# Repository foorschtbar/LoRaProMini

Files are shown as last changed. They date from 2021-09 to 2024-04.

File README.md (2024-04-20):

# LoRaProMini - A low power LoRaWAN Node

[









](https://github.com/foorschtbar/LoRaProMini)

A LoRaWAN sensor node, based on ATmega328P MCU (Arduino Pro Mini) and RFM95W/SX1276 LoRa Transceiver.

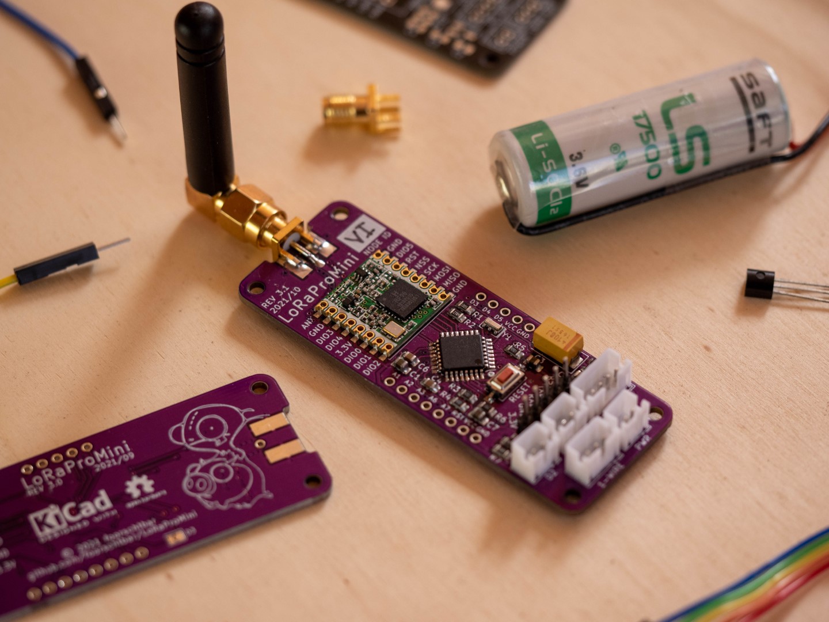
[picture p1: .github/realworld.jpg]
PCB Front Assembled


The module can be used:

- Collect various climate values with environmental sensors. See [Environmental (Weather/Clima) Sensor](#environmental-weatherclima-sensor)
- Tell if the letter carrier has put new letters in your mailbox. See [Mailbox Monitor](#mailbox-monitor)
- Notify if someone rang the doorbell
- Act a wirless button
- and many more...

## Features

- Deep sleep MCU and sensors between data transmissions
- Two interrupt inputs could use to wake up the MCU and sensors from deep sleep
- Confirmend und unconfirmend data up messages
- Ultra low power consumption. Under 10μA with all features and sensors
- Power input 3.5-6V:
  - Battery (Li-Ion or Li-SOCl2 works fine)
  - Battery with solar charger
- Sensor support
  - Bosch BME280 (humidity, barometric pressure and ambient temperature)
  - Maxim DS18B20(+)/DS18S20(+)/DS1822 1-Wire temperature sensor

### Warning

LoRaProMini does not take care of the compliance with the duty cycle limitation. Please select only transmission intervals that are within the legal limits (1%/0.1%). Please also note that the interrupt inputs may cause additional transmissions if this function is activated.

### PCB Ordering

:point_up: I still have a few PCBs left. If you are interested please contact me. Contact details can be found here: https://github.com/foorschtbar or visit my Tindie store:



## Example Applications

### Environmental (Weather/Clima) Sensor

- Download [Radiation Shield STL](https://www.prusaprinters.org/prints/73421-radiation-shield-for-diy-weather-station)
- Buy [Waterproof LED Solar Light](https://s.click.aliexpress.com/e/_9AKunB)

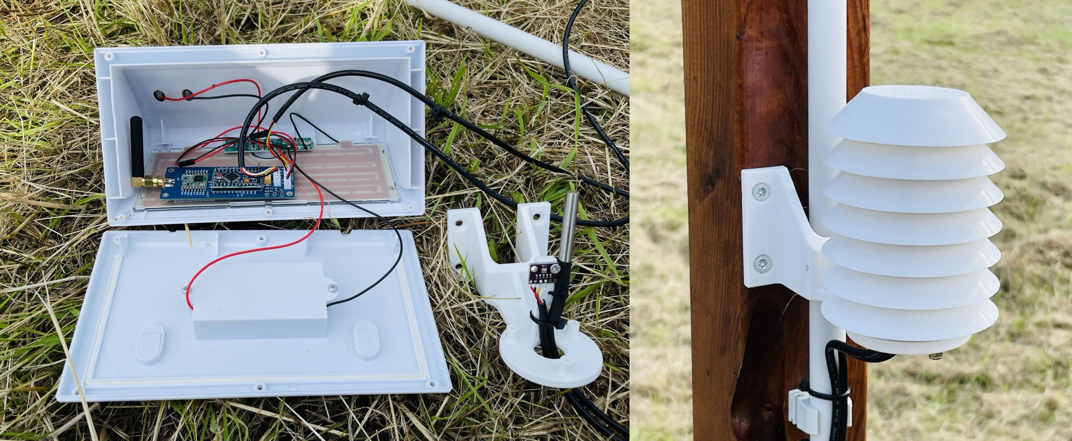
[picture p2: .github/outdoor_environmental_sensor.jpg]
Outdoor Clima Sensor


### Mailbox Monitor

- Download [Case STL](https://www.prusaprinters.org/prints/132941-case-for-lorawan-mailbox-monitor-lorapromini)
- Buy [Normally Opened Reed Switches](https://s.click.aliexpress.com/e/_AU1hN3)

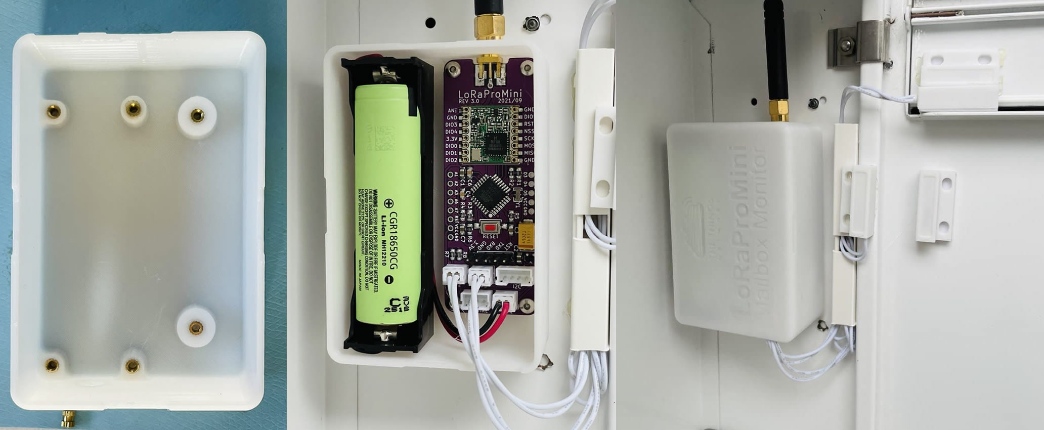
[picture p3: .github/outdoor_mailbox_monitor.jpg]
Mailbox Monitor


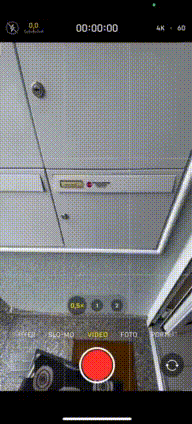
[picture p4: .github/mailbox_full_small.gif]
Mailbox Monitor
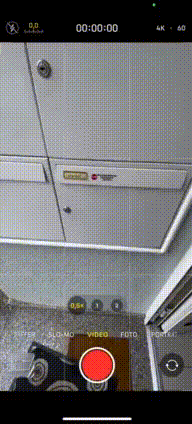
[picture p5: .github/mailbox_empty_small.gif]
Mailbox Monitor
 

## More pics

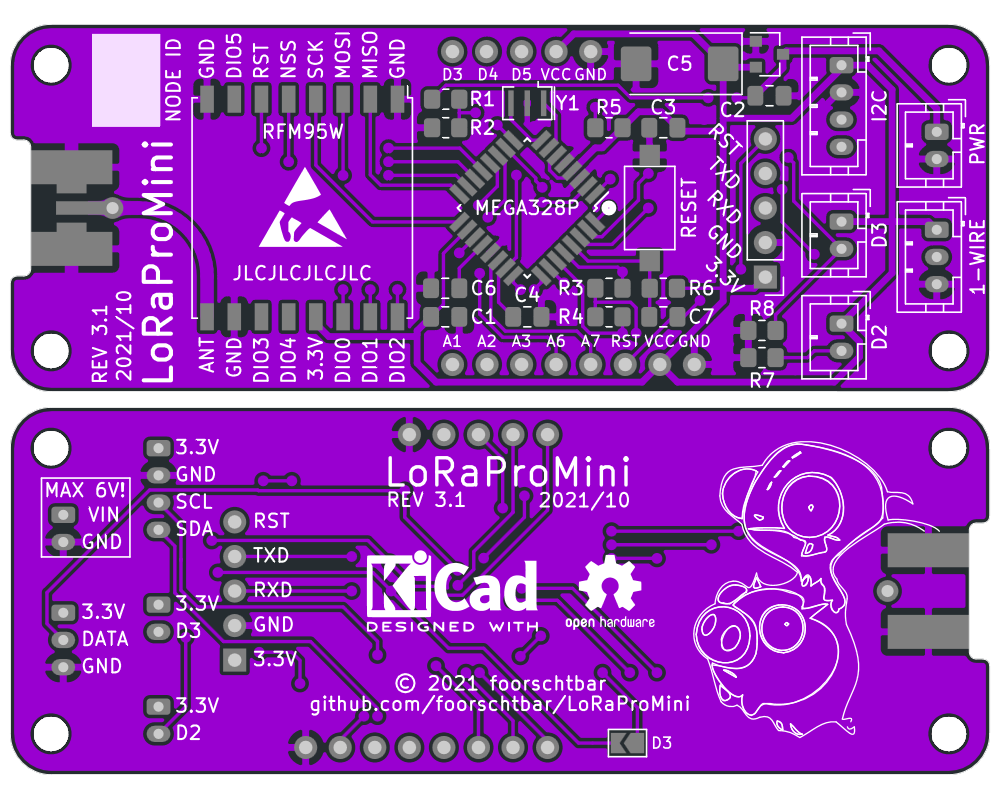
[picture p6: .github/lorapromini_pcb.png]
PCB Front and Back


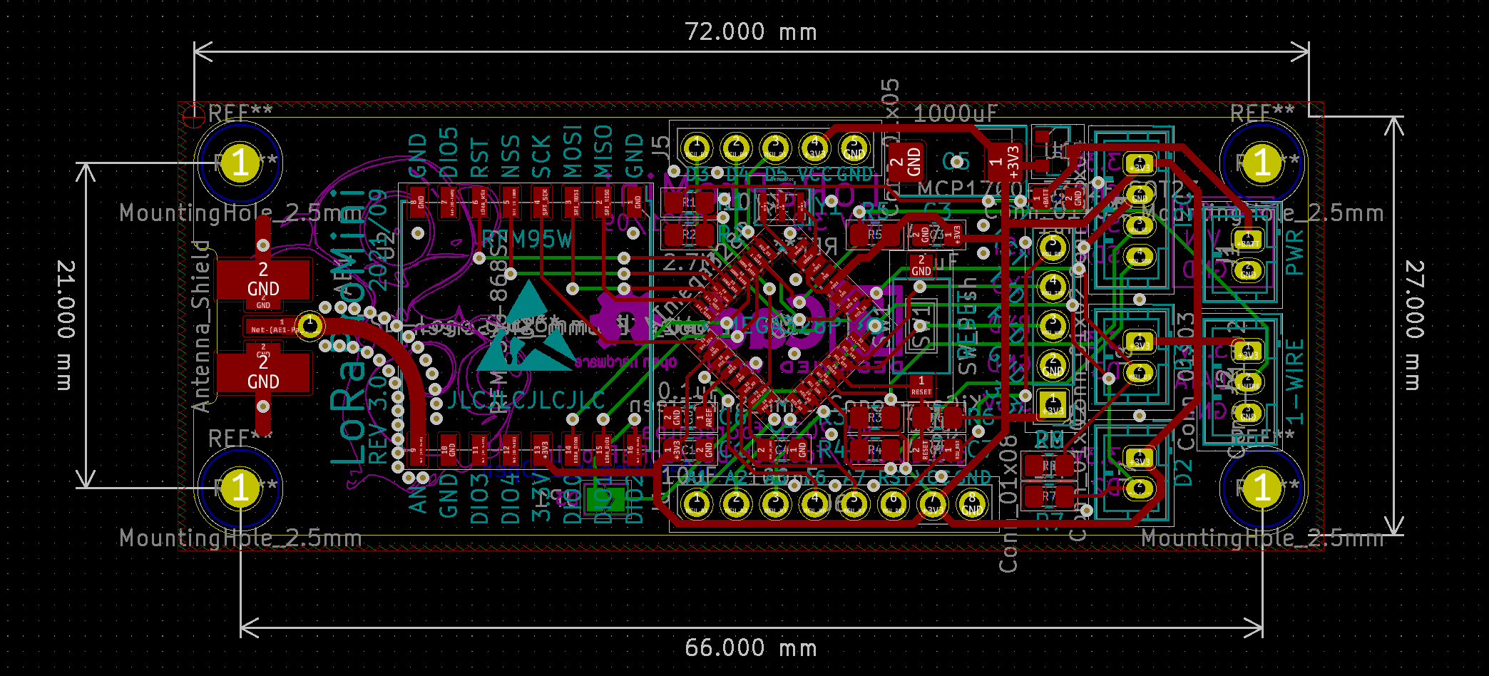
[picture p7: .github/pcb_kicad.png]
PCB KiCad


## The Things Stack configuration

- LoRaWAN version `MAC V1.0.3`

## How to use

1. Manufacture the PCB. Here you find the [Gerber](pcb) files
1. Assemble the PCB. Here you find the [Bill of Materials](https://foorschtbar.github.io/LoRaProMini/pcb/bom/ibom.html) (BOM)
   - **Attention:** The current version (v3.1) of the PCB has no ISP header! A pre-burned Atmega328P must be installed. I got one from an Arduino Pro Mini Board (3.3V 8 Mhz), because a completely assembled Arduino is cheaper than a single chip
1. Flash config firmware (See [How to flash](#how-to-flash))
1. Start voltage calibration from menu
1. Start configuration builder [Configuration Builder](https://foorschtbar.github.io/LoRaProMini/configbuilder)
1. Measure the voltage with a multimeter
1. Insert multimeter voltage and the analog value in the Volts-per-bit (VPB) calculator to get VPB factor.
1. If u have a adjustable power supply, try different voltages to find best factor. Warning: The maximum voltage is 6 Volt
1. Fill out the other fields like activation methode, session keys and EUIs
1. Write configuration to EEPROM using configuration menu
1. Check written configuration via configuration menu
1. Flash debug or release firmware (See [How to flash](#how-to-flash))
1. Finish

## How to flash

```
avrdude-F -v -c arduino -p atmega328p -P <COM PORT> -b 57600 -D -U flash:w:<FIRMWARE FILE>:i
```

Example:

```
avrdude -F -v -c arduino -p atmega328p -P COM4 -b 57600 -D -U flash:w:firmware_1.0_config.hex:i
```

## Firmware Changelog

### Version 2.7

- Fixed a problem of resetting the interrupt trigger too early.

### Version 2.6

- Second attempt to solve the unnecessary delay due to the duty cycle limitation. Overflow of timer0 freezes the MCU after around 20 transmissions.

### Version 2.5

- Fixed problem with duty cycle limitation
- Fixed MCU deepsleep inaccuracy

### Version 2.4

- An external interrupt during a transmission terminates the transmission and starts a new transmission.
- Enabled Link Check Mode

### Version 2.3

- Fixed Typo

### Version 2.2

- An additional send delay between 0 and 20s has been added to avoid overlaps between different nodes with exactly the same send interval
- Some flash memory optimizations

### Version 2.1

- Improved (debug) logging to serial output
- BME sends -127°C (link DS18x) if no sensor was found

### Version 2.0

- Added wake up trough interrupt pins
- Added option for disable interrupt pins
- Added option for confirmed uplink
- Changed LoRaWAN data up message
  - Added state of interrupt pins
  - Combined major and minor version byte into a single byte (4 bits for major and 4 bits for minor)

### Version 1.1

- Only for testing CI Pipeline

### Version 1.0

- Initial Version

## PCB Changelog

### Version 3.2

- Fixed C7 (Replaced 10uF with 100nF)

### Version 3.1

- Added white field to specify the Node ID

### Version 3.0

- Removed Arduino Pro Mini Dauther PCB
- Added ATMEGA328P direct to the PCB
- Added pins for unused GPIOs
- Added D2 and D3 with Pulldowns and connector as external interrupts (need FW v2.0 or higher)

### Version 2.2

- Added RST pin to connector for programming

### Version 2.1

- Added connector for programming

### Version 2.0

- Smaller PCB
- Rounded Edges
- Fixed issue with DS18x onboard pin mapping

### Version 1.0

- Initial PCB

## TTS Payload Formatter (formerly TTN Payload Decoder)

```javascript
function decodeUplink(input) {
  var bytes = input.bytes;

  var itrTrigger = (bytes[0] & 0x1) !== 0; // Message was triggered from interrupt (bit 0)
  var itr0 = (bytes[0] & 0x2) !== 0; // Interrupt 0 (bit 1)
  var itr1 = (bytes[0] & 0x4) !== 0; // Interrupt 1 (bit 2)
  var bat = (bytes[1] << 8) | bytes[2]; // Battery
  var fwversion = (bytes[3] >> 4) + "." + (bytes[3] & 0xf); // Firmware version
  var temp1 = (bytes[4] & 0x80 ? 0xffff << 16 : 0) | (bytes[4] << 8) | bytes[5]; // BME Temperature
  var humi1 = (bytes[6] << 8) | bytes[7]; // BME Humidity
  var press1 = (bytes[8] << 8) | bytes[9]; // BME Pressure
  var temp2 =
    (bytes[10] & 0x80 ? 0xffff << 16 : 0) | (bytes[10] << 8) | bytes[11]; // DS18x Temperature

  var mbStatus = "UNKNOWN";
  if (itr0) {
    mbStatus = "FULL";
  } else if (itr1) {
    mbStatus = "EMPTY";
  }

  return {
    data: {
      interrupts: {
        itr0: itr0,
        itr1: itr1,
        itrTrigger: itrTrigger,
      },
      extra: {
        mbStatus: mbStatus,
        mbChanged: itrTrigger,
      },
      fwversion: fwversion,
      bme: {
        temperature: temp1 / 100,
        humidity: humi1 / 100,
        pressure: press1,
      },
      ds18x: {
        temperature: temp2 / 100,
      },
      battery: bat / 100,
    },
    warnings: [],
    errors: [],
  };
}
```

## ToDo

- [ ] Go to sleep immediately when voltage is too low
- [ ] Multi point calibration for battery voltage
- [ ] Set ADR (On/Off)
- [ ] Set SF (7-12)
- [ ] Allow change of NetID
- [x] Add wake up trough interrupt pins
- [x] Move Major- and Minorversion byte to single byte. 4 bits for major and 4 bits for minor.
- [x] Add option for Confirmed Uplink to config
- [x] Add CI/CD pipeline to build firmware
- [x] Rewirte VBP calculator in Configuration Builder
- [x] Move config to EEPROM
- [x] Added special firmware to change configs
- [x] Build HTML/JS Interface to build configs
- [x] Add CRC32 check
- [x] Test ABP
- [x] Test OTAA
- [x] Deploy config tool via GitHub Pages
- [x] Fix problem when checksum in pastend config had zeros O.o
- [x] Add random EUI generator button to config tool
- [x] Parse config string to GUI fields

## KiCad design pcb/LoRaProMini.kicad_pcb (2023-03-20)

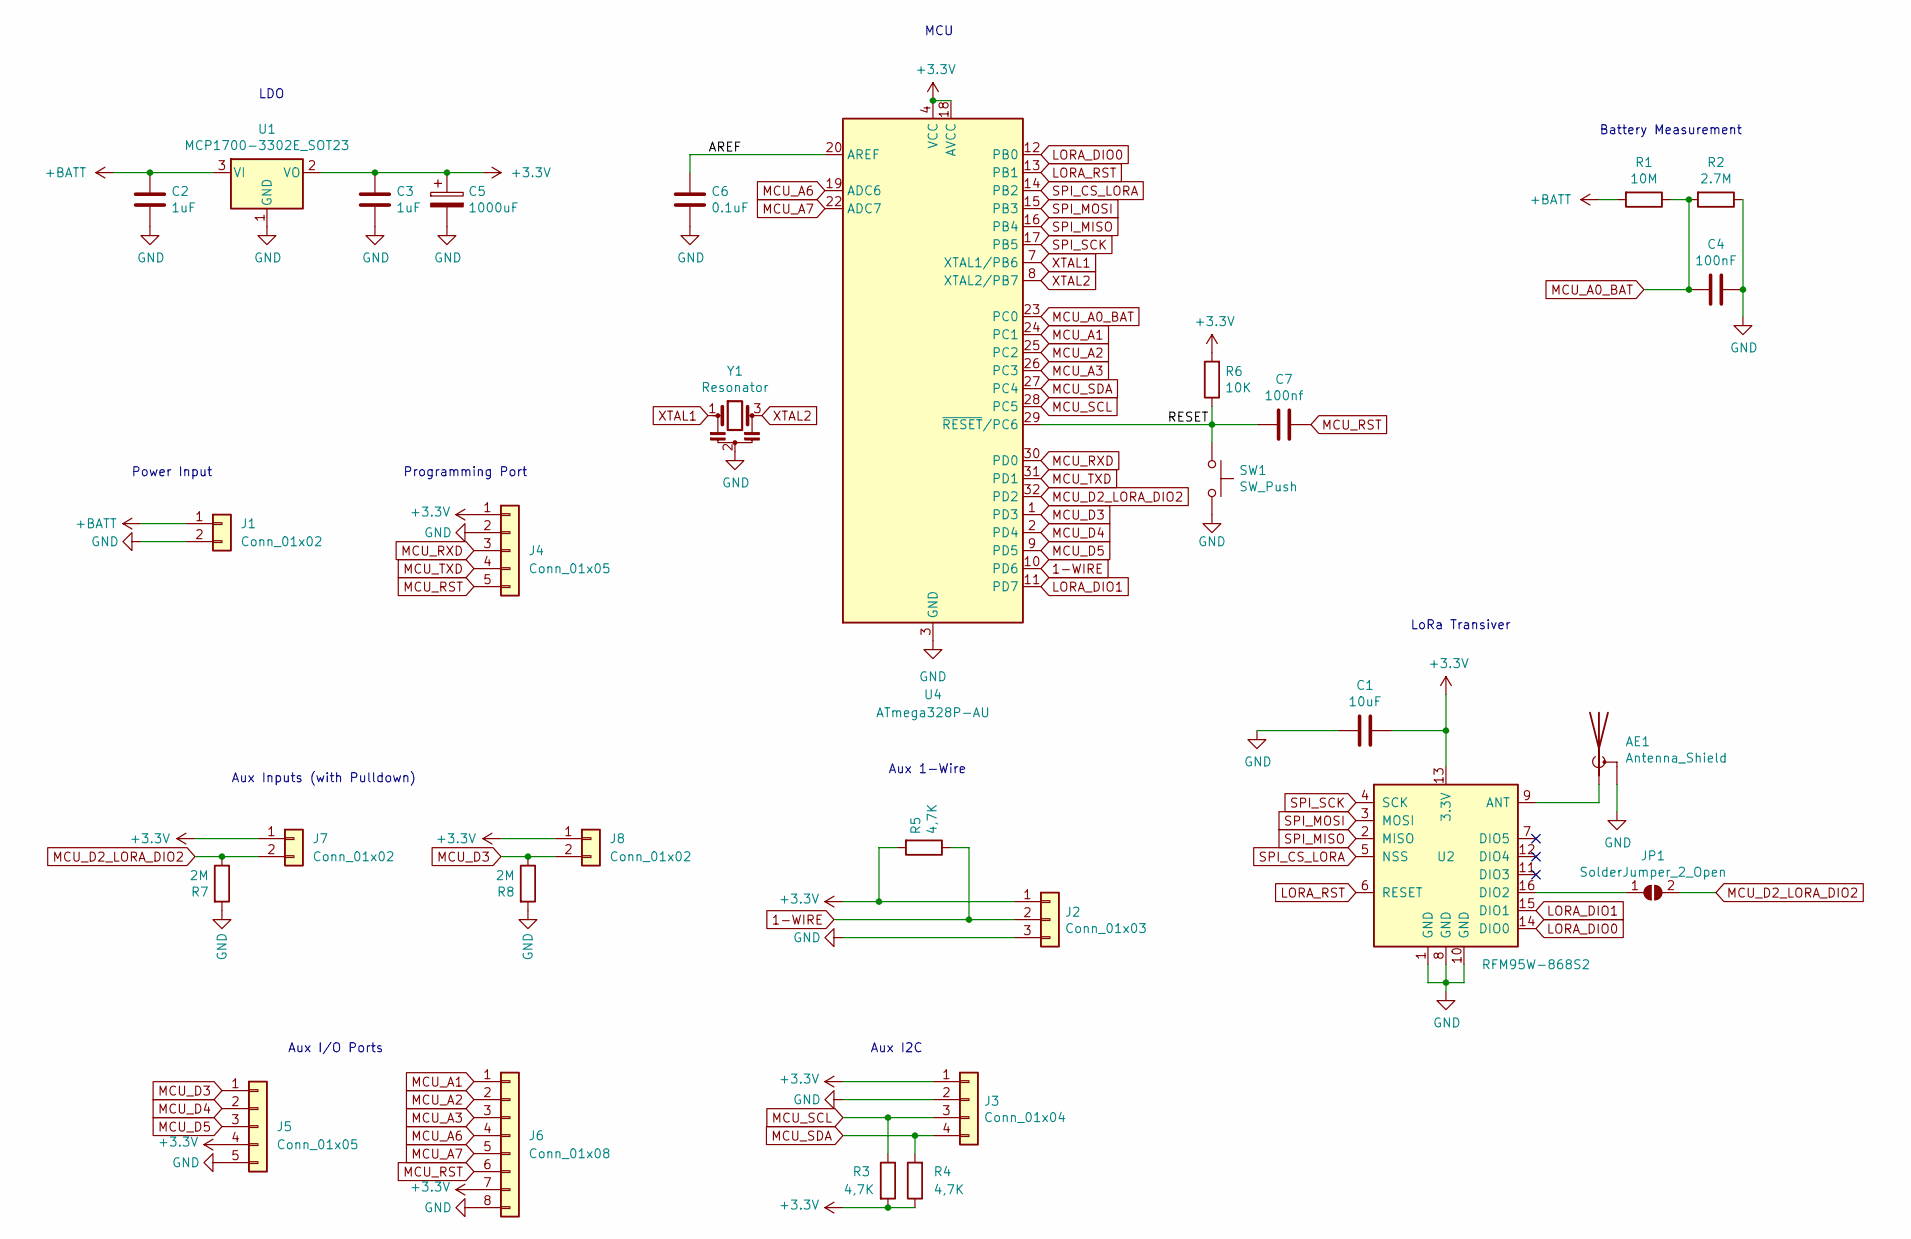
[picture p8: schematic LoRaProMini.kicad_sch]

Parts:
AE1: Antenna_Shield; Antenna_SMA_uFL
C1: 10uF; C_0805_2012Metric_Pad1.18x1.45mm_HandSolder
C2, C3: 1uF; C_0805_2012Metric_Pad1.18x1.45mm_HandSolder
C4: 100nF; C_0805_2012Metric_Pad1.18x1.45mm_HandSolder
C5: 1000uF; CP_EIA-7343-43_Kemet-X_Pad2.25x2.55mm_HandSolder
C6: 0.1uF; C_0805_2012Metric_Pad1.18x1.45mm_HandSolder
C7: 100nf; C_0805_2012Metric_Pad1.18x1.45mm_HandSolder
J1, J7, J8: Conn_01x02; JST_PH_B2B-PH-K_1x02_P2.00mm_Vertical
J2: Conn_01x03; JST_PH_B3B-PH-K_1x03_P2.00mm_Vertical
J3: Conn_01x04; JST_PH_B4B-PH-K_1x04_P2.00mm_Vertical
J4: Conn_01x05; PinHeader_1x05_P2.54mm_Vertical
J5: Conn_01x05; Holes_1x05_P2.54mm
J6: Conn_01x08; Holes_1x08_P2.54mm
JP1: SolderJumper_2_Open; SolderJumper-2_P1.3mm_Open_TrianglePad1.0x1.5mm
R1: 10M; R_0805_2012Metric_Pad1.20x1.40mm_HandSolder
R2: 2.7M; R_0805_2012Metric_Pad1.20x1.40mm_HandSolder
R3, R4, R5: 4,7K; R_0805_2012Metric_Pad1.20x1.40mm_HandSolder
R6: 10K; R_0805_2012Metric_Pad1.20x1.40mm_HandSolder
R7, R8: 2M; R_0805_2012Metric_Pad1.20x1.40mm_HandSolder
SW1: SW_Push; SW_SPST_CK_RS282G05A3
U1: MCP1700-3302E_SOT23; SOT-23
U2: RFM95W-868S2; HOPERF_RFM9XW_SMD
U4: ATmega328P-AU; TQFP-32_7x7mm_P0.8mm
Y1: Resonator; Resonator_SMD_Murata_CSTxExxV-3Pin_3.0x1.1mm

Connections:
1-WIRE: J2.2, R5.1, U4.10 (PD6)
+3.3V: C1.1, C3.1, C5.1, J2.1, J3.1, J4.1, J5.4, J6.7, J7.1, J8.1, R3.2, R4.1, R5.2, R6.2, U1.2 (VO), U2.13 (3.3V), U4.4 (VCC), U4.6 (VCC), U4.18 (AVCC)
+BATT: C2.1, J1.1, R1.2, U1.3 (VI)
/AREF: C6.1, U4.20 (AREF)
/RESET: C7.2, R6.1, SW1.1, U4.29 (~RESET/PC6)
GND: AE1.2 (Shield), C1.2, C2.2, C3.2, C4.1, C5.2, C6.2, J1.2, J2.3, J3.2, J4.2, J5.5, J6.8, R2.1, R7.2, R8.2, SW1.2, U1.1 (GND), U2.1 (GND), U2.8 (GND), U2.10 (GND), U4.3 (GND), U4.5 (GND), U4.21 (GND), Y1.2
LORA_DIO0: U2.14 (DIO0), U4.12 (PB0)
LORA_DIO1: U2.15 (DIO1), U4.11 (PD7)
LORA_RST: U2.6 (RESET), U4.13 (PB1)
MCU_A0_BAT: C4.2, R1.1, R2.2, U4.23 (PC0)
MCU_A1: J6.1, U4.24 (PC1)
MCU_A2: J6.2, U4.25 (PC2)
MCU_A3: J6.3, U4.26 (PC3)
MCU_A6: J6.4, U4.19 (ADC6)
MCU_A7: J6.5, U4.22 (ADC7)
MCU_D2_LORA_DIO2: J7.2, JP1.2 (B), R7.1, U4.32 (PD2)
MCU_D3: J5.1, J8.2, R8.1, U4.1 (PD3)
MCU_D4: J5.2, U4.2 (PD4)
MCU_D5: J5.3, U4.9 (PD5)
MCU_RST: C7.1, J4.5, J6.6
MCU_RXD: J4.3, U4.30 (PD0)
MCU_SCL: J3.3, R3.1, U4.28 (PC5)
MCU_SDA: J3.4, R4.2, U4.27 (PC4)
MCU_TXD: J4.4, U4.31 (PD1)
unnamed: AE1.1 (A), U2.9 (ANT)
unnamed: JP1.1 (A), U2.16 (DIO2)
SPI_CS_LORA: U2.5 (NSS), U4.14 (PB2)
SPI_MISO: U2.2 (MISO), U4.16 (PB4)
SPI_MOSI: U2.3 (MOSI), U4.15 (PB3)
SPI_SCK: U2.4 (SCK), U4.17 (PB5)
XTAL1: U4.7 (XTAL1/PB6), Y1.1
XTAL2: U4.8 (XTAL2/PB7), Y1.3

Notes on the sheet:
Aux 1-Wire
Aux I/O Ports
LDO
MCU
Power Input
Battery Measurement
Aux I2C
Aux Inputs (with Pulldown)
Programming Port
LoRa Transiver

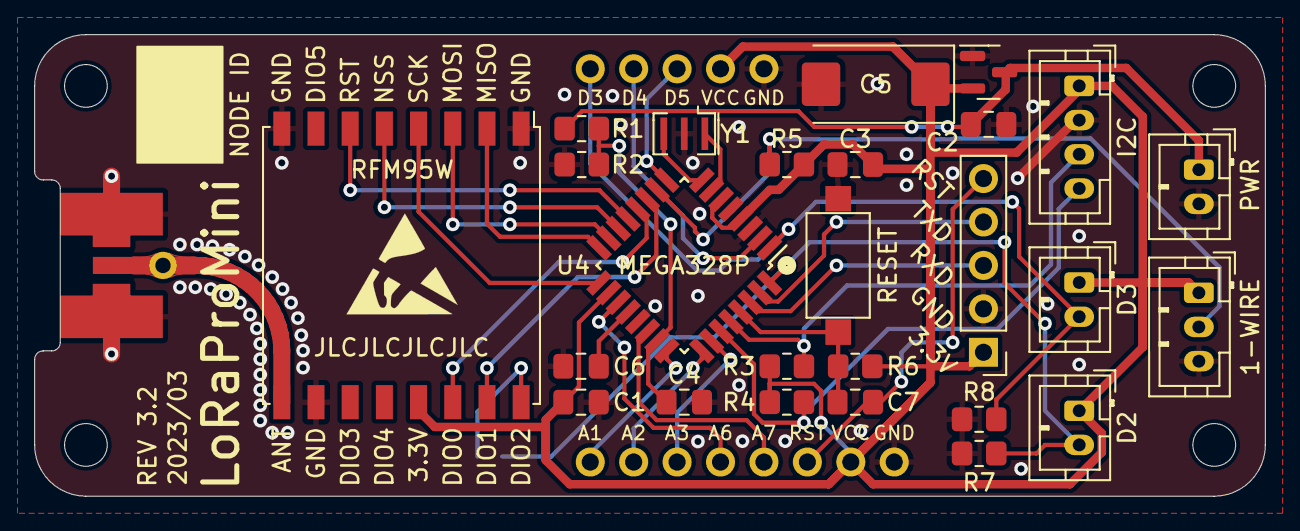
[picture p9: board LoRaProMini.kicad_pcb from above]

Board: 2 copper layers, 72.0 x 27.0 mm, 30 parts (1 on the bottom side), 32 nets.

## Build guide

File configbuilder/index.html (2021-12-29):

LoRaProMini Configuration Builder

All fields are mandatory!

Sleep time between transmissions in seconds (2 byte)

Adjustment for voltage divider (Volts per bit, 4 bytes)

Minimum voltage for operation, otherwise the node continues sleeping (4 bytes)

Wakeup from sleep through external interrupt pins (1 byte)

Confirmation for Data Up (1 byte)

Activation method (1 byte)

Network Session Key (MSB, 16 bytes)

App Session Key (MSB, 16 bytes)

Device Address (MSB, 4 bytes)

Application EUI (MSB, 8 bytes)

Device EUI (MSB, 8 bytes)

Application Key (MSB, 16 bytes)

Configuration

Size without checksum

Size with checksum

Checksum (CRC32)

© 2021 foorschtbar | GitHub (https://github.com/foorschtbar/LoRaProMini)

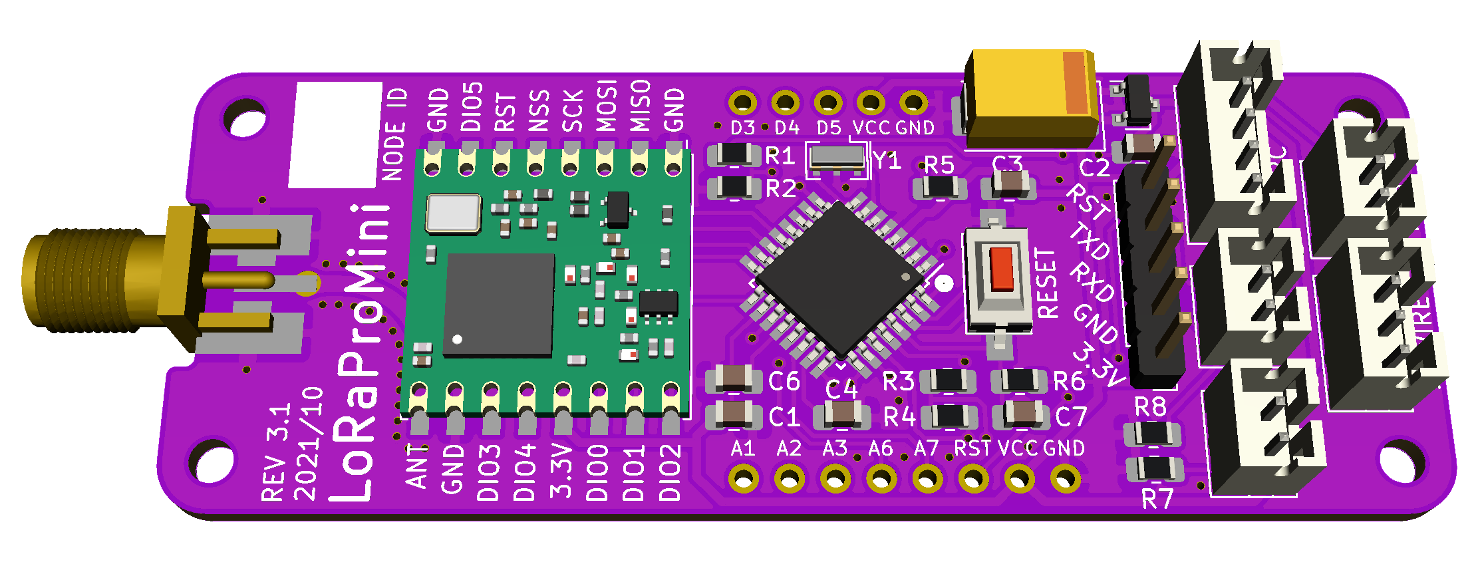
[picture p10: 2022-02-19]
.github/pcb_front_assembled.png

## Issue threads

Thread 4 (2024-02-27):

3.2 PCB Gerbers produce a 3.1 version at PCB house

radiohound, 2024-02-27:
Hello,

When I upload the 3.2 gerber zip file, my board house shows me a silkscreen with v3.1 on it. It looks like some layer or layers need to be updated to 3.2.

Closed 2024-02-29.

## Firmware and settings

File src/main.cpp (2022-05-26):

#include <Arduino.h>
#include <lmic.h>
#include <hal/hal.h>
#include <SPI.h>
#include <Wire.h>
#include <LowPower.h>
#include <OneWire.h>
#include <TinyDallas.h>
#include <TinyBME.h>
#include <EEPROM.h>
#include <CRC32.h>

// ++++++++++++++++++++++++++++++++++++++++
//
// CONSTANTS
//
// ++++++++++++++++++++++++++++++++++++++++

// LoRa module pins
#define LORA_DIO0 8
#define LORA_DIO1 7
#define LORA_DIO2 LMIC_UNUSED_PIN
#define LORA_RESET 9
#define LORA_CS SS

// 1-Wire Bus
#define ONEWIREBUS 6

// External interrupt pins
#define INTERRUPT_PIN0 2
#define INTERRUPT_PIN1 3

// Battery
#define BAT_SENSE_PIN A0 // Analoge Input Pin

// BME I2C Adresses
#define I2C_ADR_BME 0x76

// Voltage calibration interval
#define VOL_DEBUG_INTERVAL 1000 // in ms

// Start address in EEPROM for structure 'cfg'
#define CFG_START 0

// Config size
#define CFG_SIZE 82
#define CFG_SIZE_WITH_CHECKSUM 86

// LORA MAX RANDOM SEND DELAY
#define LORA_MAX_RANDOM_SEND_DELAY 20

// ++++++++++++++++++++++++++++++++++++++++
//
// LOGGING
//
// ++++++++++++++++++++++++++++++++++++++++

#ifdef LOG_DEBUG
#define log_d(s, ...) Serial.print(s, ##__VA_ARGS__);
#define log_d_ln(s, ...) Serial.println(s, ##__VA_ARGS__);
#define logHex_d(b, c) printHex(b, c);
const boolean LOG_DEBUG_ENABLED = true;
#else
#define log_d(s, ...)
#define log_d_ln(s, ...)
#define logHex_d(b, c)
const boolean LOG_DEBUG_ENABLED = false;
#endif

// ++++++++++++++++++++++++++++++++++++++++
//
// LIBS
//
// ++++++++++++++++++++++++++++++++++++++++

OneWire oneWire(ONEWIREBUS);
TinyDallas ds(&oneWire);
TinyBME bme;

// Dallas temp sensor(s)
DeviceAddress dsSensor; // Holds later first sensor found at boot.

// ++++++++++++++++++++++++++++++++++++++++
//
// ENUMS
//
// ++++++++++++++++++++++++++++++++++++++++

enum _activationMethode
{
  OTAA = 1,
  ABP = 2
};

enum _StateByte
{
  STATE_ITR_TRIGGER = 0b0001,
  STATE_ITR0 = 0b0010,
  STATE_ITR1 = 0b0100,
};

// ++++++++++++++++++++++++++++++++++++++++
//
// VARS
//
// ++++++++++++++++++++++++++++++++++++++++

#ifdef CONFIG_MODE
const boolean CONFIG_MODE_ENABLED = true;
#else
const boolean CONFIG_MODE_ENABLED = false;
#endif

// LoRa LMIC
static osjob_t sendjob;
const lmic_pinmap lmic_pins = {
    .nss = LORA_CS,
    .rxtx = LMIC_UNUSED_PIN,
    .rst = LORA_RESET,
    .dio = {LORA_DIO0, LORA_DIO1, LORA_DIO2},
};

typedef struct
{
  uint8_t CONFIG_IS_VALID;          // 1 byte
  uint16_t SLEEPTIME;               // 2 byte - (Deep) Sleep time between data acquisition and transmission
  float BAT_SENSE_VPB;              // 4 byte - Volts per Bit. See documentation
  float BAT_MIN_VOLTAGE;            // 4 byte - Minimum voltage for operation, otherwise the node continues to sleep
  uint8_t WAKEUP_BY_INTERRUPT_PINS; // 1 byte - 0 = Disabled, 1 = Enabled
  uint8_t CONFIRMED_DATA_UP;        // 1 byte - 0 = Unconfirmed Data Up, 1 = Confirmed Data Up
  uint8_t ACTIVATION_METHOD;        // 1 byte - 1 = OTAA, 2 = ABP

  // ABP
  u1_t NWKSKEY[16]; // 16 byte - NwkSKey, network session key in big-endian format (aka msb).
  u1_t APPSKEY[16]; // 16 byte - AppSKey, application session key in big-endian format (aka msb).
  u4_t DEVADDR;     //  4 byte - DevAddr, end-device address in big-endian format (aka msb)
  // OTAA
  u1_t APPEUI[8];  //  8 byte - EUIs must be little-endian format, so least-significant-byte (aka lsb)
  u1_t DEVEUI[8];  //  8 byte - EUIs must be in little-endian format, so least-significant-byte (aka lsb)
  u1_t APPKEY[16]; // 16 byte - AppSKey, application session key in big-endian format (aka msb).

} configData_t;
configData_t cfg; // Instance 'cfg' is a global variable with 'configData_t' structure now

volatile boolean wakedFromISR0 = false;
volatile boolean wakedFromISR1 = false;
unsigned long lastPrintTime = 0;
unsigned long prepareCount = 0;
boolean TXCompleted = false;
boolean foundBME = false; // BME Sensor found. To skip reading if no sensor is attached
boolean foundDS = false;  // DS19x Sensor found. To skip reading if no sensor is attached
byte pinState = 0x0;
boolean doSend = false;

// These callbacks are used in over-the-air activation
void os_getArtEui(u1_t *buf)
{
  memcpy(buf, cfg.APPEUI, 8);
}
void os_getDevEui(u1_t *buf)
{
  memcpy(buf, cfg.DEVEUI, 8);
}
void os_getDevKey(u1_t *buf)
{
  memcpy(buf, cfg.APPKEY, 16);
}

// ++++++++++++++++++++++++++++++++++++++++
//
// MAIN CODE
//
// ++++++++++++++++++++++++++++++++++++++++

void clearSerialBuffer()
{
  while (Serial.available())
  {
    Serial.read();
  }
}

void wakeUp0()
{
  wakedFromISR0 = true;
}

void wakeUp1()
{
  wakedFromISR1 = true;
}

float readBat()
{
  uint16_t value = 0;
  uint8_t numReadings = 5;

  for (uint8_t i = 0; i < numReadings; i++)
  {
    value = value + analogRead(BAT_SENSE_PIN);

    // 1ms pause adds more stability between reads.
    delay(1);
  }

  value = value / numReadings;

  float batteryV = value * cfg.BAT_SENSE_VPB;
  if (CONFIG_MODE_ENABLED)
  {
    Serial.print(F("Analoge voltage: "));
    Serial.print(((1.1 / 1024.0) * value), 2);
    Serial.print(F(" V | Analoge value: "));
    Serial.print(value);
    Serial.print(F(" ("));
    Serial.print(((100.0 / 1023.0) * value), 1);
    Serial.print(F("% of Range) | Battery voltage: "));
    Serial.print(batteryV, 1);
    Serial.print(F(" V ("));
    Serial.print(batteryV, 2);
    Serial.print(F(" V, VPB="));
    Serial.print(cfg.BAT_SENSE_VPB, 10);
    Serial.println(F(")"));
  }

  return batteryV;
}

void printHex(byte buffer[], size_t arraySize)
{
  unsigned c;
  for (size_t i = 0; i < arraySize; i++)
  {
    c = buffer[i];

    if (i != 0)
      Serial.write(32); // Space

    c &= 0xff;
    if (c < 16)
      Serial.write(48); // 0
    Serial.print(c, HEX);
  }
}

void readConfig()
{
  EEPROM.get(CFG_START, cfg);
}

void setConfig()
{
  byte cfgbuffer[CFG_SIZE_WITH_CHECKSUM];
  char buffer[3];
  char *pEnd;
  uint32_t crc_data = 0;
  CRC32 crc;

  for (uint8_t i = 0; i < CFG_SIZE_WITH_CHECKSUM; i++)
  {
    if (!Serial.readBytes(buffer, 2))
    {
      break;
    }

    // added null-terminator for strtol
    buffer[3] = '\0';

    // convert null-terminated char buffer with hex values to int
    cfgbuffer[i] = (byte)strtol(buffer, &pEnd, 16);

    // Add bytes to crc calculation
    if (i < CFG_SIZE)
    {
      // Add hex chars from buffer without null-terminator
      crc.update(buffer, 2);
    }
    else
    {
      // Store checksum from serial input
      // later compare
      crc_data <<= 8;
      crc_data |= cfgbuffer[i];
    }

    // Pad to 8 bit
    // Add zero prefix to serial output
    cfgbuffer[i] &= 0xff;
    if (cfgbuffer[i] < 16)
      Serial.write(48); // 0

    Serial.print(cfgbuffer[i], HEX);
    Serial.print(" ");
  }

  Serial.println();

  Serial.print(F("> CHECKSUM (Serial Input): 0x"));
  Serial.print(crc_data, HEX);
  Serial.println();

  uint32_t crc_calculated = crc.finalize();
  Serial.print(F("> CHECKSUM (Calculated):   0x"));
  Serial.println(crc_calculated, HEX);

  if (crc_data == crc_calculated)
  {

    Serial.println(F("> Checksum correct. Configuration saved!"));

    for (uint8_t i = CFG_START; i < CFG_SIZE; i++)
    {
      EEPROM.write(i, (uint8_t)cfgbuffer[i]);
    }

    readConfig();
  }
  else
  {
    Serial.println(F("> INVALID CHECKSUM! Process aborted! "));
  }
}

void showConfig(bool raw = false)
{
  Serial.print(F("> CONFIG_IS_VALID: "));
  if (cfg.CONFIG_IS_VALID == 1)
  {
    Serial.println(F("yes"));
  }
  else
  {
    Serial.println(F("no"));
  }
  Serial.print(F("> SLEEPTIME: "));
  Serial.println(cfg.SLEEPTIME, DEC);
  Serial.print(F("> BAT_SENSE_VPB: "));
  Serial.println(cfg.BAT_SENSE_VPB, DEC);
  Serial.print(F("> BAT_MIN_VOLTAGE: "));
  Serial.println(cfg.BAT_MIN_VOLTAGE, DEC);
  Serial.print(F("> WAKEUP_BY_INTERRUPT_PINS: "));
  switch (cfg.WAKEUP_BY_INTERRUPT_PINS)
  {
  case 0:
    Serial.println(F("Disabled"));
    break;
  case 1:
    Serial.println(F("Enabled"));
    break;
  default:
    Serial.println(F("Unkown"));
    break;
  }
  Serial.print(F("> CONFIRMED_DATA_UP: "));
  switch (cfg.CONFIRMED_DATA_UP)
  {
  case 0:
    Serial.println(F("Unconfirmed Data Up"));
    break;
  case 1:
    Serial.println(F("Confirmed Data Up"));
    break;
  default:
    Serial.println(F("Unkown"));
    break;
  }
  Serial.print(F("> ACTIVATION_METHOD: "));
  switch (cfg.ACTIVATION_METHOD)
  {
  case 1:
    Serial.println(F("OTAA"));
    break;
  case 2:
    Serial.println(F("ABP"));
    break;
  default:
    Serial.println(F("Unkown"));
    break;
  }
  Serial.print(F("> NWKSKEY (MSB): "));
  printHex(cfg.NWKSKEY, sizeof(cfg.NWKSKEY));
  Serial.print(F("\n> APPSKEY (MSB): "));
  printHex(cfg.APPSKEY, sizeof(cfg.APPSKEY));
  Serial.print(F("\n> DEVADDR (MSB): "));
  Serial.print(cfg.DEVADDR, HEX);
  Serial.print(F("\n> APPEUI (LSB): "));
  printHex(cfg.APPEUI, sizeof(cfg.APPEUI));
  Serial.print(F("\n> DEVEUI (LSB): "));
  printHex(cfg.DEVEUI, sizeof(cfg.DEVEUI));
  Serial.print(F("\n> APPKEY (MSB): "));
  printHex(cfg.APPKEY, sizeof(cfg.APPKEY));
  Serial.println();

  if (raw)
  {
    Serial.print(F("> RAW ("));
    Serial.print((uint32_t)sizeof(cfg), DEC);
    Serial.print(F(" bytes): "));
    byte c;
    for (uint8_t i = CFG_START; i < sizeof(cfg); i++)
    {
      c = EEPROM.read(i);
      c &= 0xff;
      if (c < 16)
        Serial.write(48); // 0
      Serial.print(c, HEX);
      Serial.print(" ");
    }
    Serial.println();
  }
}

void eraseConfig()
{
  for (uint8_t i = CFG_START; i < sizeof(cfg); i++)
  {
    EEPROM.write(i, 0);
  }
}

void serialWait()
{
  while (!Serial.available())
  {
    yield();
    delay(50);
  }
}

void serialMenu()
{
  unsigned long timer = millis();

  Serial.println(F("\n== CONFIG MENU =="));
  Serial.println(F("[1] Show current config"));
  Serial.println(F("[2] Set new config"));
  Serial.println(F("[3] Erase current config"));
  Serial.println(F("[4] Voltage calibration"));
  Serial.print(F("Select: "));
  serialWait();

  if (Serial.available() > 0)
  {
    switch (Serial.read())
    {
    case '1':
      Serial.println(F("\n\n== SHOW CONFIG =="));
      showConfig(true);
      break;

    case '2':
      Serial.println(F("\n\n== SET CONFIG =="));
      Serial.print(F("Past new config: "));
      serialWait();
      if (Serial.available() > 0)
      {
        setConfig();
      }
      break;

    case '3':
      Serial.println(F("\n\n== ERASE CONFIG =="));
      Serial.print(F("Are you sure you want to erase the EEPROM? [y]es or [n]o: "));
      serialWait();
      Serial.println();
      if (Serial.available() > 0)
      {
        if (Serial.read() == 'y')
        {
          eraseConfig();
          Serial.println(F("Successfull!"));
          readConfig();
        }
        else
        {
          Serial.println(F("Aborted!"));
        }
      }
      break;

    case '4':
      Serial.println(F("\n\n== VOLTAGE CALIBRATION =="));
      while (!Serial.available())
      {
        if (millis() - timer > VOL_DEBUG_INTERVAL)
        {
          readBat();
          timer = millis();
        }
      }

      break;
    }
  }
  clearSerialBuffer();
}

void do_send(osjob_t *j)
{
  // Check if there is not a current TX/RX job running
  if (LMIC.opmode & OP_TXRXPEND)
  {
    // Serial.println(F("OP_TXRXPEND, not sending"));
  }
  else
  {
    // Unsigned 16 bits integer, 0 up to 65,535
    uint16_t bat = 0;

    // Battery
    bat = readBat() * 100;

    // Signed 16 bits integer, -32,768 up to +32,767
    int16_t temp1 = -127 * 100;
    int16_t temp2 = -127 * 100;

    // Unsigned 16 bits integer, 0 up to 65,535
    uint16_t humi1 = 0;
    uint16_t press1 = 0;

    // Read sensor values von BME280
    // and multiply by 100 to effectively keep 2 decimals
    if (foundBME)
    {
      bme.takeForcedMeasurement();
      temp1 = bme.readTemperature() * 100;
      humi1 = bme.readHumidity() * 100;
      press1 = bme.readPressure() / 100.0F; // p [300..1100]
    }

    // Read sensor value form 1-Wire sensor
    // and multiply by 100 to effectively keep 2 decimals
    if (foundDS)
    {
      ds.requestTemperatures(); // Send the command to get temperatures
      temp2 = ds.getTempC(dsSensor) * 100;
    }

    byte buffer[12];
    buffer[0] = pinState;
    buffer[1] = bat >> 8;
    buffer[2] = bat;
    buffer[3] = (VERSION_MAJOR << 4) | (VERSION_MINOR & 0xf);
    buffer[4] = temp1 >> 8;
    buffer[5] = temp1;
    buffer[6] = humi1 >> 8;
    buffer[7] = humi1;
    buffer[8] = press1 >> 8;
    buffer[9] = press1;
    buffer[10] = temp2 >> 8;
    buffer[11] = temp2;

    log_d("Prepare pck #");
    log_d_ln(++prepareCount);
    // log_d(F("> FW: v"));
    // log_d(VERSION_MAJOR);
    // log_d(F("."));
    // log_d(VERSION_MINOR);
    // log_d(F("> Batt: "));
    // log_d_ln(bat);
    // log_d(F("> Pins: "));
    // log_d_ln(buffer[0], BIN);
    // log_d(F("> BME Temp: "));
    // log_d_ln(temp1);
    // log_d(F("> BME Humi: "));
    // log_d_ln(humi1);
    // log_d(F("> BME Pres: "));
    // log_d_ln(press1);
    // log_d(F("> DS18x Temp: "));
    // log_d_ln(temp2);
    log_d(F("> Payload: "));
    logHex_d(buffer, sizeof(buffer));
    log_d_ln();

    // Print first debug messages in loop immediately
    lastPrintTime = 0;

    TXCompleted = false;

    // Prepare upstream data transmission at the next possible time.
    LMIC_setTxData2(1, buffer, sizeof(buffer), cfg.CONFIRMED_DATA_UP);
    log_d_ln(F("Pck queued"));
  }
}

void lmicStartup()
{
  // Reset the MAC state. Session and pending data transfers will be discarded.
  LMIC_reset();

  if (cfg.ACTIVATION_METHOD == ABP)
  {
    // Set static session parameters. Instead of dynamically establishing a session
    // by joining the network, precomputed session parameters are be provided.
    LMIC_setSession(0x13, cfg.DEVADDR, cfg.NWKSKEY, cfg.APPSKEY);

#if defined(CFG_eu868)
    // Set up the channels used by the Things Network, which corresponds
    // to the defaults of most gateways. Without this, only three base
    // channels from the LoRaWAN specification are used, which certainly
    // works, so it is good for debugging, but can overload those
    // frequencies, so be sure to configure the full frequency range of
    // your network here (unless your network autoconfigures them).
    // Setting up channels should happen after LMIC_setSession, as that
    // configures the minimal channel set. The LMIC doesn't let you change
    // the three basic settings, but we show them here.
    LMIC_setupChannel(0, 868100000, DR_RANGE_MAP(DR_SF12, DR_SF7), BAND_CENTI);  // g-band
    LMIC_setupChannel(1, 868300000, DR_RANGE_MAP(DR_SF12, DR_SF7B), BAND_CENTI); // g-band
    LMIC_setupChannel(2, 868500000, DR_RANGE_MAP(DR_SF12, DR_SF7), BAND_CENTI);  // g-band
    LMIC_setupChannel(3, 867100000, DR_RANGE_MAP(DR_SF12, DR_SF7), BAND_CENTI);  // g-band
    LMIC_setupChannel(4, 867300000, DR_RANGE_MAP(DR_SF12, DR_SF7), BAND_CENTI);  // g-band
    LMIC_setupChannel(5, 867500000, DR_RANGE_MAP(DR_SF12, DR_SF7), BAND_CENTI);  // g-band
    LMIC_setupChannel(6, 867700000, DR_RANGE_MAP(DR_SF12, DR_SF7), BAND_CENTI);  // g-band
    LMIC_setupChannel(7, 867900000, DR_RANGE_MAP(DR_SF12, DR_SF7), BAND_CENTI);  // g-band
    LMIC_setupChannel(8, 868800000, DR_RANGE_MAP(DR_FSK, DR_FSK), BAND_MILLI);   // g2-band
// TTN defines an additional channel at 869.525Mhz using SF9 for class B
// devices' ping slots. LMIC does not have an easy way to define set this
// frequency and support for class B is spotty and untested, so this
// frequency is not configured here.
#elif defined(CFG_us915) || defined(CFG_au915)
    // NA-US and AU channels 0-71 are configured automatically
    // but only one group of 8 should (a subband) should be active
    // TTN recommends the second sub band, 1 in a zero based count.
    // https://github.com/TheThingsNetwork/gateway-conf/blob/master/US-global_conf.json
    LMIC_selectSubBand(1);
#elif defined(CFG_as923)
// Set up the channels used in your country. Only two are defined by default,
// and they cannot be changed.  Use BAND_CENTI to indicate 1% duty cycle.
// LMIC_setupChannel(0, 923200000, DR_RANGE_MAP(DR_SF12, DR_SF7),  BAND_CENTI);
// LMIC_setupChannel(1, 923400000, DR_RANGE_MAP(DR_SF12, DR_SF7),  BAND_CENTI);

// ... extra definitions for channels 2..n here
#elif defined(CFG_kr920)
// Set up the channels used in your country. Three are defined by default,
// and they cannot be changed. Duty cycle doesn't matter, but is conventionally
// BAND_MILLI.
// LMIC_setupChannel(0, 922100000, DR_RANGE_MAP(DR_SF12, DR_SF7),  BAND_MILLI);
// LMIC_setupChannel(1, 922300000, DR_RANGE_MAP(DR_SF12, DR_SF7),  BAND_MILLI);
// LMIC_setupChannel(2, 922500000, DR_RANGE_MAP(DR_SF12, DR_SF7),  BAND_MILLI);

// ... extra definitions for channels 3..n here.
#elif defined(CFG_in866)
// Set up the channels used in your country. Three are defined by default,
// and they cannot be changed. Duty cycle doesn't matter, but is conventionally
// BAND_MILLI.
// LMIC_setupChannel(0, 865062500, DR_RANGE_MAP(DR_SF12, DR_SF7),  BAND_MILLI);
// LMIC_setupChannel(1, 865402500, DR_RANGE_MAP(DR_SF12, DR_SF7),  BAND_MILLI);
// LMIC_setupChannel(2, 865985000, DR_RANGE_MAP(DR_SF12, DR_SF7),  BAND_MILLI);

// ... extra definitions for channels 3..n here.
#else
#error Region not supported
#endif

    // Disable link check validation
    LMIC_setLinkCheckMode(0);
    // Disable ADR
    LMIC_setAdrMode(0);

    // TTN uses SF9 for its RX2 window.
    LMIC.dn2Dr = DR_SF9;

    // Set data rate and transmit power for uplink (note: txpow seems to be ignored by the library)
    LMIC_setDrTxpow(DR_SF7, 14);

    // #else
  }
  else
  {
    LMIC_setClockError(MAX_CLOCK_ERROR * 5 / 100); // fix OTAA joining for Arduino Pro Mini (https://github.com/matthijskooijman/arduino-lmic#problems-with-downlink-and-otaa)
  }
  // #endif
}
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
void loop()
{

  if (CONFIG_MODE_ENABLED)
  {
    serialMenu();
  }
  else
  {

    os_runloop_once();

    // Previous TX is complete and also no critical jobs pending in LMIC
    if (TXCompleted)
    {
      // Going to sleep
      boolean sleep = true;
      while (sleep)
      {
        do_sleep(cfg.SLEEPTIME);
        if (readBat() >= cfg.BAT_MIN_VOLTAGE)
        {
          sleep = false;
        }
        else
        {
          log_d_ln(F("Bat to low!"));
        }
      }

      handleISR();

      // sleep ended. do next transmission
      doSend = true;
    }
    if (lastPrintTime == 0 || lastPrintTime + 1000 < millis())
    {
      log_d_ln(F("> Can't sleep"));
      lastPrintTime = millis();
    }

    handleISR();

    if (doSend)
    {
      doSend = false;
      do_send(&sendjob);
      reset_itr_trigger_state();
    }
  }
}

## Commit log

2021-03-26 Added KiCad Project
    [LoRaProMini.kicad_pcb, LoRaProMini.sch]
2021-03-27 Added sample config file
2021-03-28 Added A6/A7 to Arduino Pro Mini Pinout
2021-03-28 Updated KiCad Project
    [LoRaProMini.kicad_pcb, LoRaProMini.sch]
2021-04-24 Added battery voltage measurement
2021-05-08 Added the first PCB Layout
    [LoRaProMini.kicad_pcb, LoRaProMini.sch]
2021-05-08 Update PCB
    [LoRaProMini.kicad_pcb, LoRaProMini.sch]
2021-05-15 Added code for 1-Wire sensors
2021-05-16 Replaced DallasTemperature with a own, smaller library
    [main.cpp]
2021-05-21 Removed fixed DS18B20 address. Now first found sensor will be used
    [main.cpp]
2021-05-21 Added a Voltage Calibration Mode
    [Volts-per-Bit-Calculator.xls]
2021-05-21 Added "continue sleep if voltage is to low" feature
2021-05-21 Updated PCB
    [LoRaProMini.kicad_pcb, LoRaProMini.sch]
2021-05-22 Added Gerber files
    [LoRaProMini-B_Cu.gbr, LoRaProMini-B_Mask.gbr, LoRaProMini-B_Paste.gbr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]
2021-06-05 Added REV 2.0 PCB
    - Resized PCB
    - Fixed DS18x orientation
    [LoRaProMini-B_Cu.gbr, LoRaProMini-B_Mask.gbr, LoRaProMini-B_Paste.gbr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]
2021-07-03 Added REV 2.1 PCB
    [LoRaProMini-B_Cu.gbr, LoRaProMini-B_Mask.gbr, LoRaProMini-B_Paste.gbr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]
2021-07-05 Replaced REV 2.1 PCB
    [LoRaProMini-B_Cu.gbr, LoRaProMini-B_Mask.gbr, LoRaProMini-B_Paste.gbr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]
2021-07-11 Tested and fixed OTAA
    - and code cleanup
    [main.cpp]
2021-07-16 Fixed problems with pasted config strings
    [main.cpp]
2021-07-16 Added VBP calculator to configuration builder
    [Volts-per-Bit-Calculator.xls]
2021-08-31 Added RST Pin to Programmer Interface
    [LoRaProMini-B_Cu.gbr, LoRaProMini-B_Mask.gbr, LoRaProMini-B_Paste.gbr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]
2021-09-20 Replaced Arduino Pro Mini Dauther PCB
    - Added ATmega328P direct to the PCB
    - Added pins for unsed GPIOs
    - Added D2 and D3 with Pulldown and connector as external Interrupts
    [LoRaProMini-B_Cu.gbr, LoRaProMini-B_Mask.gbr, LoRaProMini-B_Paste.gbr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]
2021-10-06 Added BOM
2021-10-06 Renamed pcb und docu folder
    [LoRaProMini-B_Cu.gbr, LoRaProMini-B_Mask.gbr, LoRaProMini-B_Paste.gbr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]
2021-10-07 Send -127°C if no BME sensor was found
2021-10-14 Added white field to PCB to specify the Node ID
    [LoRaProMini-B_Cu.gbr, LoRaProMini-B_Mask.gbr, LoRaProMini-B_Paste.gbr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]
2021-10-15 Added random send delay
    - An additional send delay between 0 and 20s has been added to avoid overlaps between different nodes with exactly the same send interval
    - Some Flash memory optimizations
    [main.cpp]
2021-12-23 Updated iBOM for PCB Rev 3.1
2021-12-31 - Interrupt and ADR improvments
2022-02-14 Fixed MCU deepsleep inaccuracy
    [main.cpp]
2022-02-15 Fixed problem with duty cycle limitation
    [main.cpp]
2022-05-09 bugfix: Reset state ItrTrigger after sending
    [main.cpp]
2022-05-26 Fixed issue with Config Builder WebUI buttons
2023-03-20 Removed KiCad V6 Files
    [LoRaProMini.sch]
2023-03-20 Added project based footprints
2023-03-20 Fixed C7 (10uf --> 100nF)
    [LoRaProMini.kicad_pcb, LoRaProMini.kicad_sch]
2023-03-20 Upgraded Gerbs to REV3.2
    [LoRaProMini-B_Cu.gbr, LoRaProMini-B_Mask.gbr, LoRaProMini-B_Paste.gbr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]
2024-02-29 Removes duplicated silkscreen from gerbers (fixes #4)
    [LoRaProMini-B_SilkS.gbr, LoRaProMini-F_SilkS.gbr]

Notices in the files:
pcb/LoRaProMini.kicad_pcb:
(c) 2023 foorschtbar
